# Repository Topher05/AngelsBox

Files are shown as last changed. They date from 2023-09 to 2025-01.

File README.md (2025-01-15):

# AngelsBox Leverless Controller

A custom-designed leverless controller for fighting games, inspired by the Flatbox project. This project includes PCB designs created in KiCad and 3D models designed in Fusion 360. Keyboard part footprints from external repositories are utilized for precision and compatibility.

## Features

- **Custom PCB Design**: Designed using KiCad, tailored for leverless controller configurations.
- **3D Models**: Created in Fusion 360 for the case and structural components.
- **Keyboard Compatibility**: Leveraging community-driven footprints for key switches and other keyboard-related parts.
- **Fighting Game Optimized**: Designed with ergonomics and precision in mind for competitive play.
- **Firmware**: Uses [GP2040-CE](https://gp2040-ce.info/web-configurator/) for firmware configuration and setup.

## Contents

1. **PCB Design**:
   - KiCad project files for the controller PCB.
   - Schematic and layout files.
   - Gerber files ready for manufacturing.

2. **3D Models**:
   - Fusion 360 files and exported STL models.
   - Case and structural parts for assembly.

3. **Documentation**:
   - Build instructions and assembly tips.
   - Information about external repositories used for keyboard footprints.

## Requirements

- **KiCad**: For viewing and editing PCB design files.
- **Fusion 360**: For modifying or inspecting the 3D models.
- **3D Printer**: To print the case and other structural parts.
- **PCB Manufacturer**: To fabricate the PCB using the provided Gerber files.
- **Firmware Configurator**: Access [GP2040-CE Web Configurator](https://gp2040-ce.info/web-configurator/) for firmware setup.

## Setup and Assembly

1. **PCB Fabrication**:
   - Send the provided Gerber files to your preferred PCB manufacturer.

2. **3D Printing**:
   - Print the STL files using a 3D printer.
   - Ensure proper filament material based on desired durability and aesthetics.

3. **Assembly**:
   - Solder components onto the fabricated PCB.
   - Assemble the 3D-printed case and secure the PCB inside.
   - Install key switches and other hardware components.

4. **Firmware Configuration**:
   - Use the [GP2040-CE Web Configurator](https://gp2040-ce.info/web-configurator/) to configure the firmware for your controller.

5. **Testing**:
   - Connect the controller to a compatible device.
   - Verify inputs and functionality through fighting game or test software.

## Contributions

This project is open for contributions! If you have improvements or suggestions, feel free to submit pull requests or create issues.

## Acknowledgments

- Thanks to the creators of the Flatbox project for inspiration.
- Gratitude to the contributors of open-source keyboard footprint repositories.

## License

This project is licensed under [MIT License](LICENSE).

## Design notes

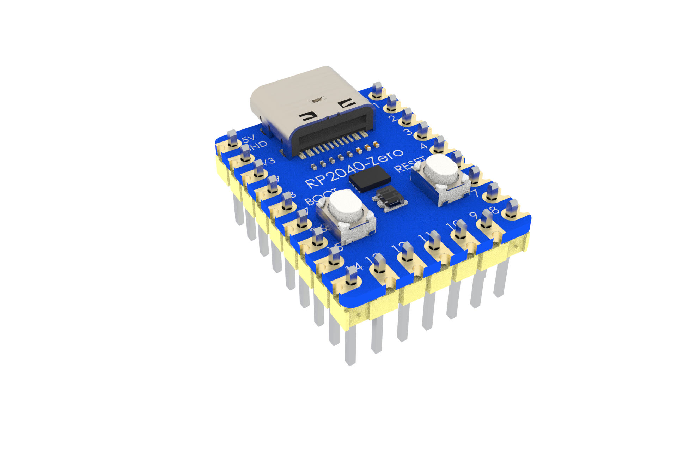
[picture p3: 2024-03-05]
rp2040-zero-2.snapshot.6/RP2040.14.png

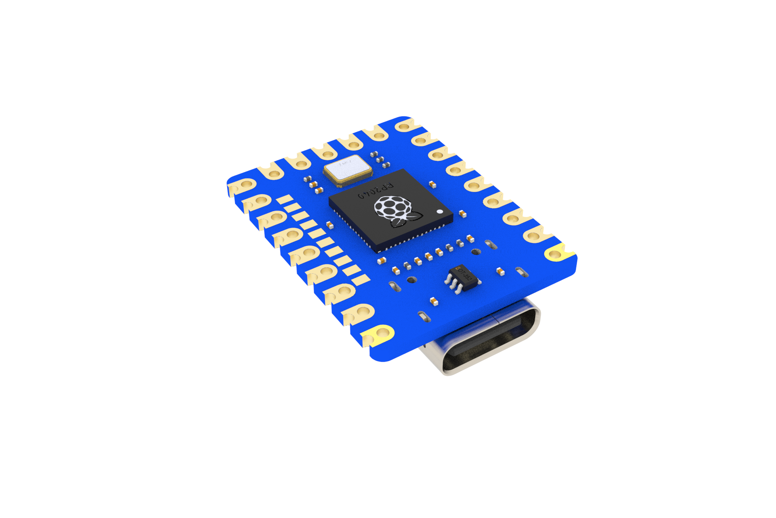
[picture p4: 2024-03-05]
rp2040-zero-2.snapshot.6/RP2040.15.png

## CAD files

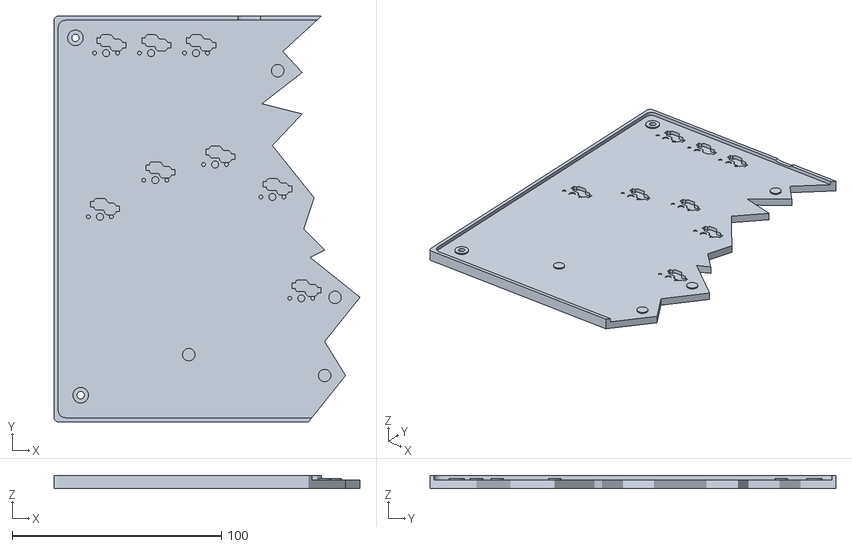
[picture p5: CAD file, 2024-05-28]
AngelsBoxBottomLeft.stl
146.4 x 194.1 x 6.00

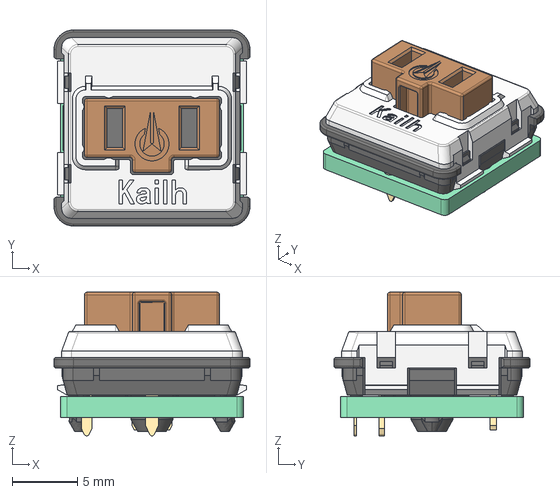
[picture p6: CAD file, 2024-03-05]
kailh-choc-low-profile-switch-1.snapshot.3/Kailh Choc Low Profile Switch.step
15.0 x 15.0 x 11.0 mm

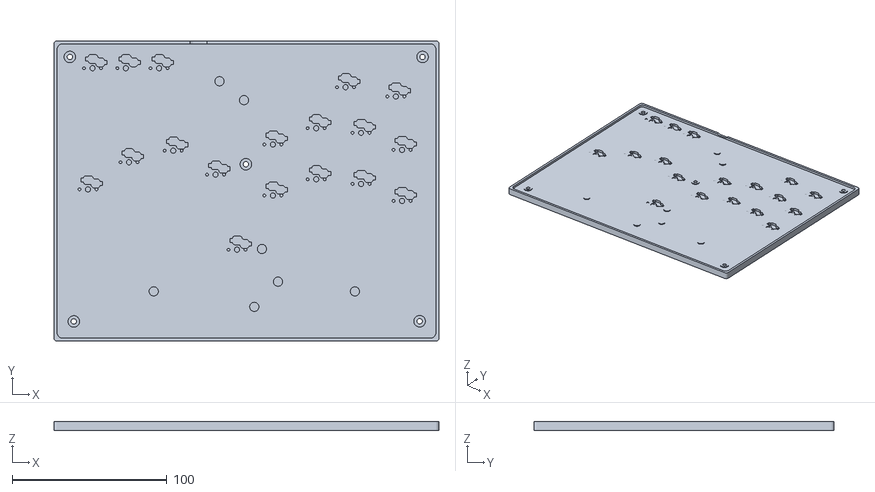
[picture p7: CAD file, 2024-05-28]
AngelsBoxBottom.stl
248.8 x 194.1 x 6.00

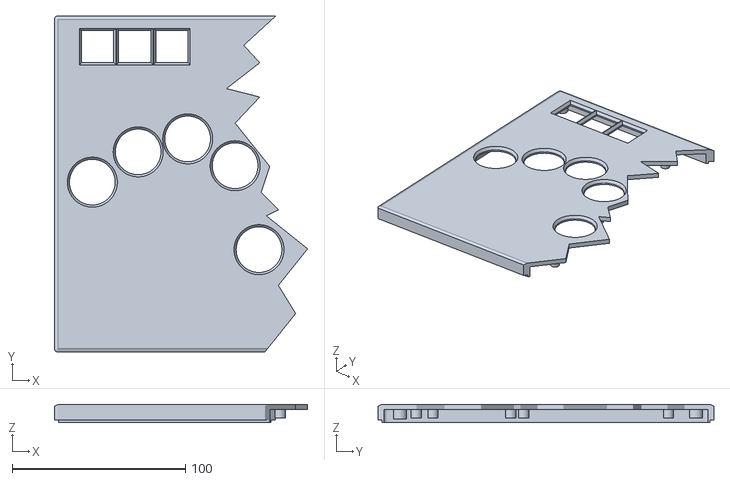
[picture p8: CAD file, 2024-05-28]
AngelsBoxTopLeft.stl
146.4 x 194.1 x 10.4

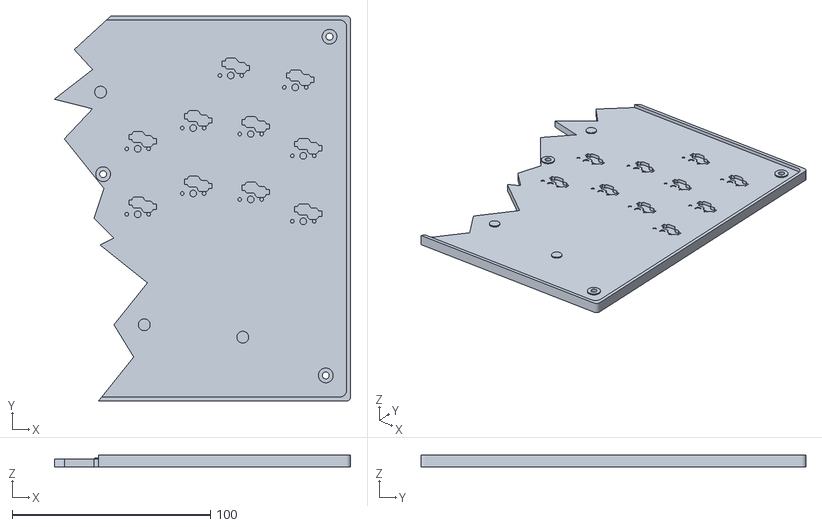
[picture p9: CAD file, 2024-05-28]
AngelsBoxBottomRight.stl
149.4 x 194.1 x 6.00

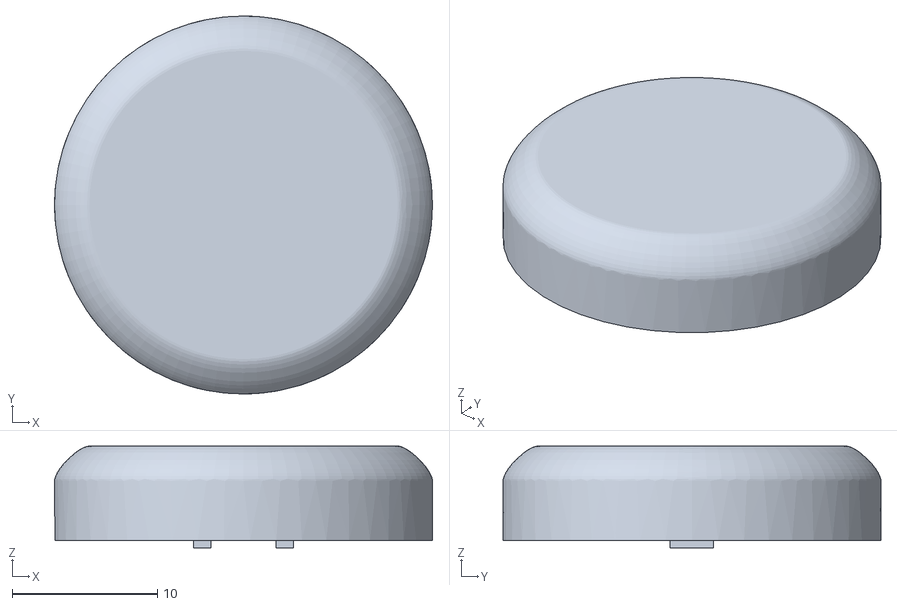
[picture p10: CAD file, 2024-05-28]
Rounded_KeyCap.stl
26.0 x 26.0 x 7.01

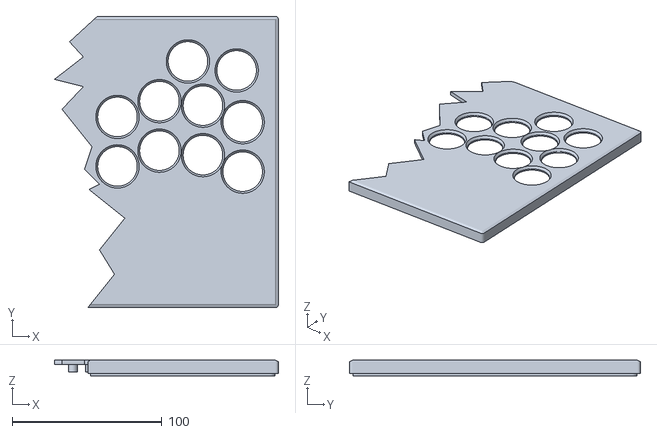
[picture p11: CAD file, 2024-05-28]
AngelsBoxTopRight.stl
149.4 x 194.1 x 10.4

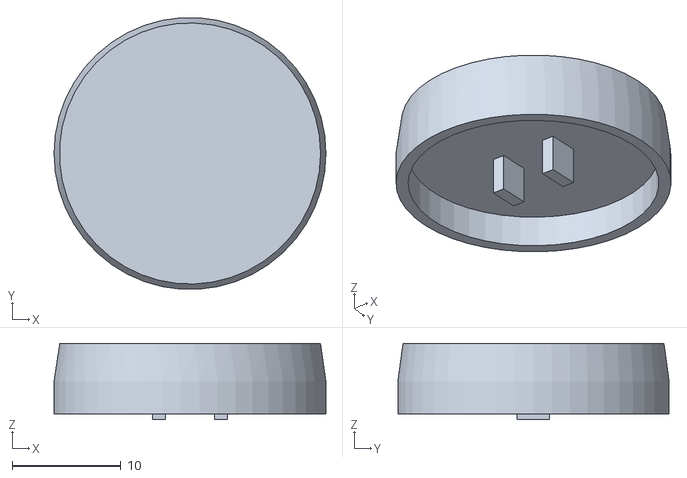
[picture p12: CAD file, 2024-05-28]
CircleKeyCap.stl
25.0 x 24.9 x 7.00

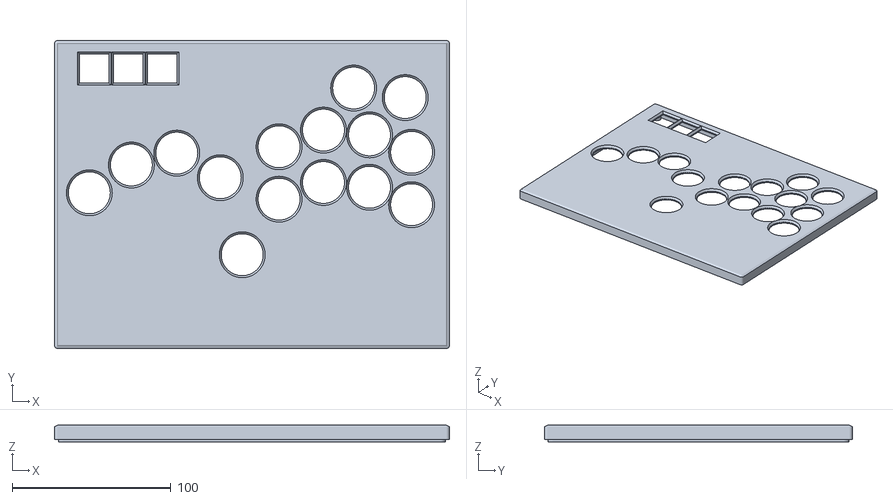
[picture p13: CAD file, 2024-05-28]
AngelsBoxTop.stl
248.8 x 194.1 x 10.4

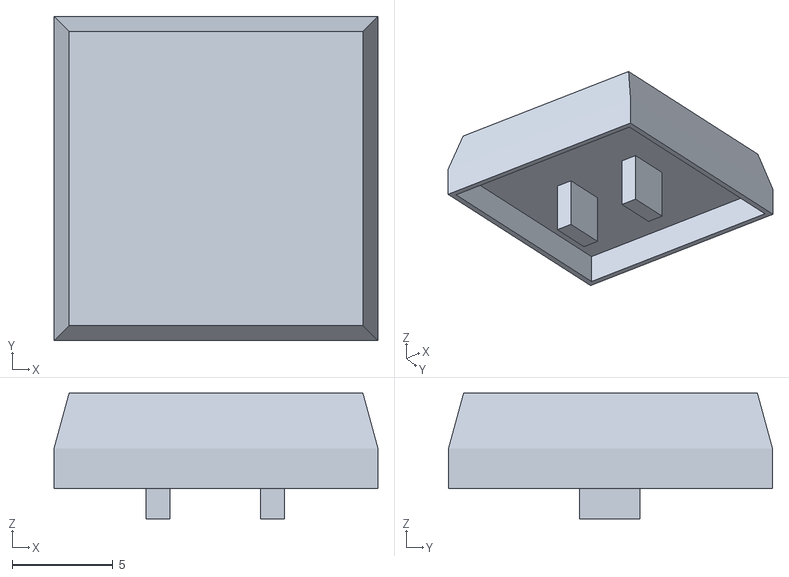
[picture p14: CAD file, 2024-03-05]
SquareKeycap.stl
16.1 x 16.1 x 6.25

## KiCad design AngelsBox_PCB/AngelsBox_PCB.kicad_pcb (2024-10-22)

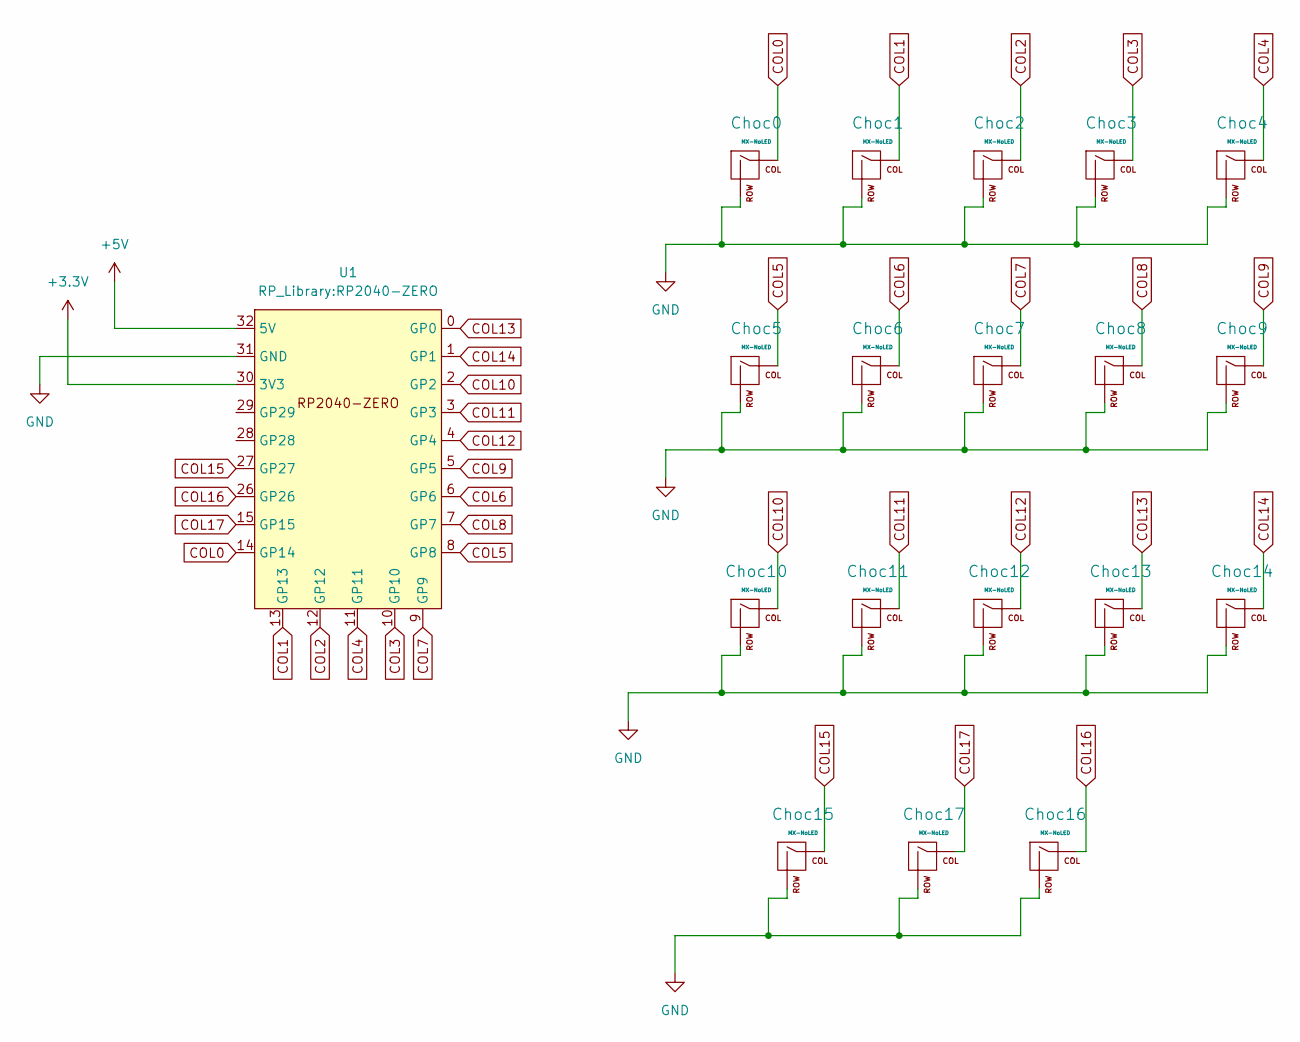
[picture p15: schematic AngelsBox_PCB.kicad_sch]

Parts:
Choc0, Choc1, Choc2, Choc3, Choc4, Choc5, Choc6, Choc7, Choc8, Choc9, Choc10, Choc11, Choc12, Choc13, Choc14: MX-NoLED; Kailh_Choc_Hotswap-CircleDesign
Choc15, Choc16, Choc17: MX-NoLED; KailhChoc-1U-Hotswap
U1: RP2040-ZERO

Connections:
+3.3V: U1.30 (3V3)
+5V: U1.32 (5V)
COL0: Choc0.1 (COL), U1.14 (GP14)
COL1: Choc1.1 (COL), U1.13 (GP13)
COL2: Choc2.1 (COL), U1.12 (GP12)
COL3: Choc3.1 (COL), U1.10 (GP10)
COL4: Choc4.1 (COL), U1.11 (GP11)
COL5: Choc5.1 (COL), U1.8 (GP8)
COL6: Choc6.1 (COL), U1.6 (GP6)
COL7: Choc7.1 (COL), U1.9 (GP9)
COL8: Choc8.1 (COL), U1.7 (GP7)
COL9: Choc9.1 (COL), U1.5 (GP5)
COL10: Choc10.1 (COL), U1.2 (GP2)
COL11: Choc11.1 (COL), U1.3 (GP3)
COL12: Choc12.1 (COL), U1.4 (GP4)
COL13: Choc13.1 (COL), U1.0 (GP0)
COL14: Choc14.1 (COL), U1.1 (GP1)
COL15: Choc15.1 (COL), U1.27 (GP27)
COL16: Choc16.1 (COL), U1.26 (GP26)
COL17: Choc17.1 (COL), U1.15 (GP15)
GND: Choc0.2 (ROW), Choc1.2 (ROW), Choc2.2 (ROW), Choc3.2 (ROW), Choc4.2 (ROW), Choc5.2 (ROW), Choc6.2 (ROW), Choc7.2 (ROW), Choc8.2 (ROW), Choc9.2 (ROW), Choc10.2 (ROW), Choc11.2 (ROW), Choc12.2 (ROW), Choc13.2 (ROW), Choc14.2 (ROW), Choc15.2 (ROW), Choc16.2 (ROW), Choc17.2 (ROW), U1.31 (GND)

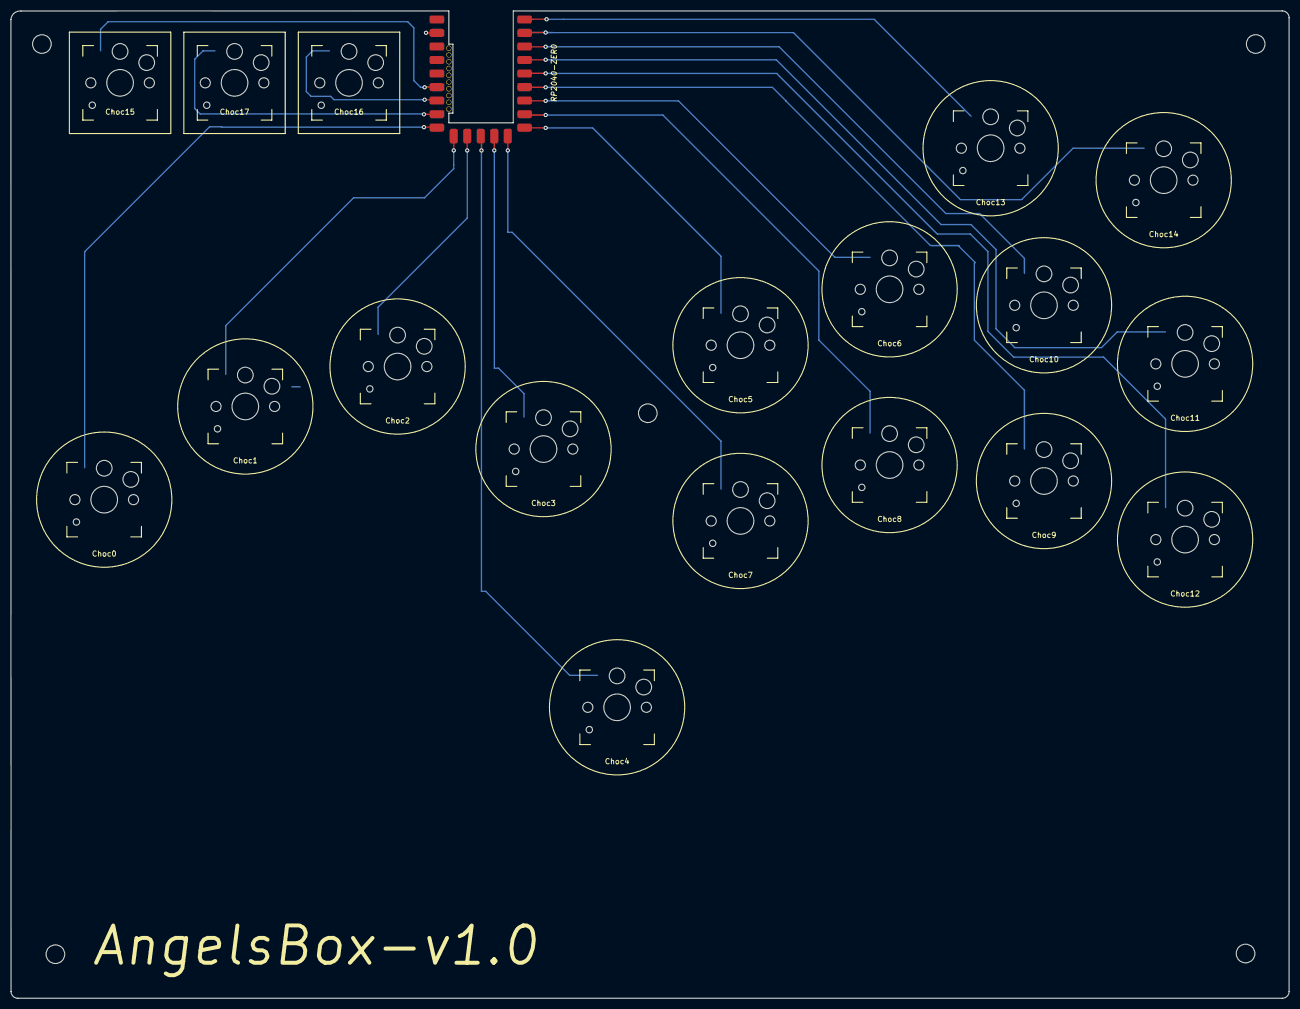
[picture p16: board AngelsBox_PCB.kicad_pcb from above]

Board: 2 copper layers, 240.1 x 185.4 mm, 19 parts (0 on the bottom side), 19 nets.

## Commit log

2023-08-31 Foot print for rp2040-zero
2023-09-02 First Schematic
    [AngelsBox_PCB.kicad_sch, bumwings_v001.kicad_sch]
2023-09-04 first pcb commit
    [AngelsBox_PCB.kicad_pcb, AngelsBox_PCB.kicad_sch, FlatBox_PCB.kicad_pcb]
2023-09-06 Adding hotswap sockets
2024-03-05 Version 1.0 Adds first completed pcb. Adds Gerber files for pcb. Adds 3d stl models for the pcb and first version of keycaps.
    [AngelsBox_PCB-B_Cu.gbl, AngelsBox_PCB-B_Mask.gbs, AngelsBox_PCB-B_Paste.gbp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]
2024-05-28 Adding small updates and a dome key cap
    [AngelsBoxBottom.stl, AngelsBoxBottomLeft.stl, AngelsBoxBottomRight.stl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]
2024-10-22 small change to the foot prints for the key switches to support choc v1 and v2
    [AngelsBox_PCB.kicad_pcb, AngelsBox_PCB.kicad_sch]
